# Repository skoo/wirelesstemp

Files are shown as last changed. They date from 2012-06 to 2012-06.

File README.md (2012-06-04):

wirelesstemp
============

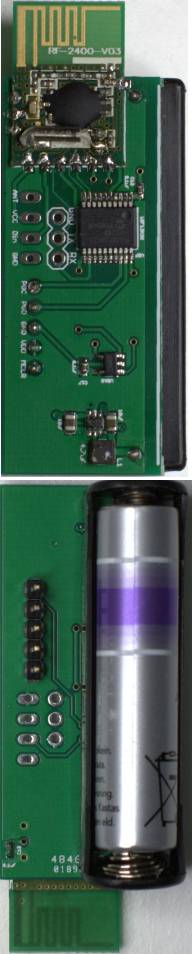
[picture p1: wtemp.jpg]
Wirelesstemp board


wirelesstemp is a wireless temperature sensor with following components:

- Microchip 18f13k22 microcontroller
- Microchip TC77 Thermal sensor with SPI interface
- RF-2400-V03 RF transmitter
- TPS61221 low input voltage boost converter
- 1.5 AAA battery

This 1.5V AAA battery operated temperature sensor sends measurement once each 65.5 seconds.
Sensor should operate for more than one year based on following measurements/assumptions:

- AAA battery holds 1000mAh.
- Sleep state consumes 90uA/65.5s
- Active state 40mA/15ms.

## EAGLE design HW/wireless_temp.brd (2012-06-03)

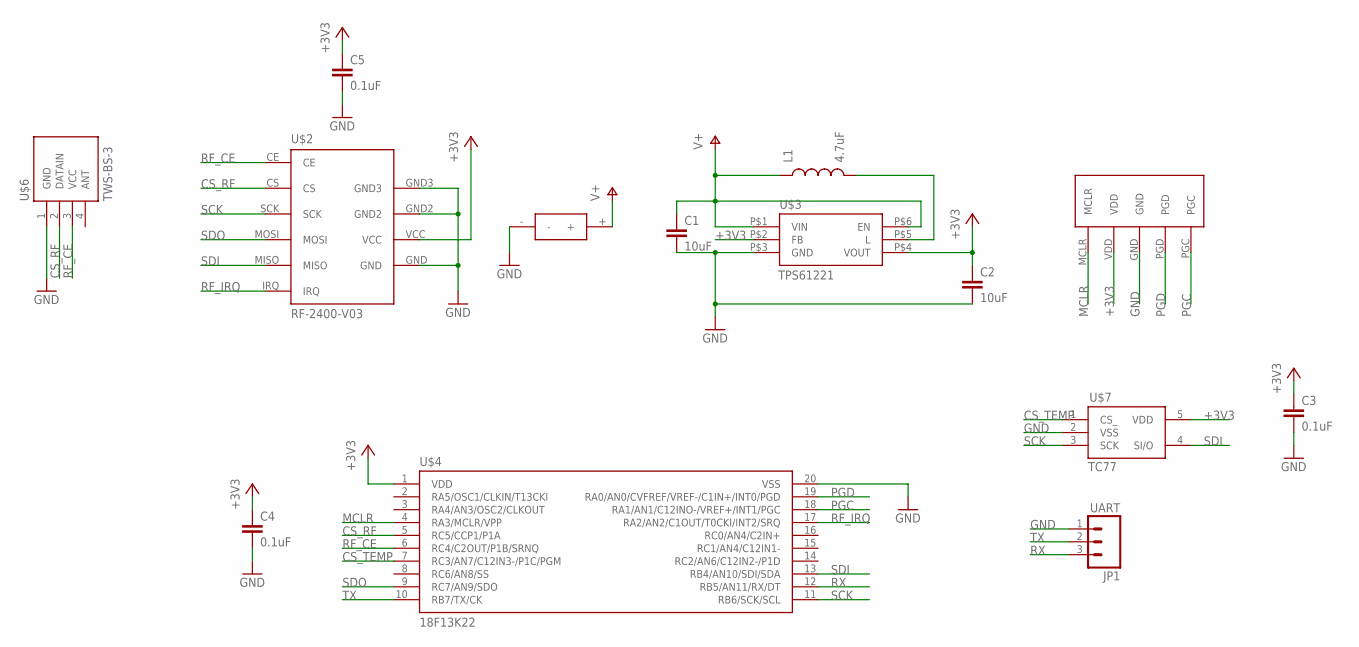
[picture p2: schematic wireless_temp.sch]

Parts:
C1, C2: 10uF; 0805
C3, C4, C5: 0.1uF; 0402-CAP
JP1: UART; 1X03
L1: 4.7uF; NR3015T
U$1: BAT_HOLDER; AAA
U$2: RF-2400-V03
U$3: TPS61221; SO6
U$4: 18F13K22; SSOP20
U$5: PIC-ICSP; ICSP
U$6: TWS-BS-3
U$7: TC77; SOT23-5

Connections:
+3V3: C2.1, C3.1, C4.1, C5.1, U$2.VCC, U$3.P$2 (FB), U$3.P$4 (VOUT), U$4.1 (VDD), U$5.VDD, U$7.5 (VDD)
CS_RF: U$2.CS, U$4.5 (RC5/CCP1/P1A), U$6.2 (DATAIN)
CS_TEMP: U$4.7 (RC3/AN7/C12IN3-/P1C/PGM), U$7.1 (CS_)
GND: C1.2, C2.2, C3.2, C4.2, C5.2, JP1.1, U$1.-, U$2.GND, U$2.GND2, U$2.GND3, U$3.P$3 (GND), U$4.20 (VSS), U$5.GND, U$6.1 (GND), U$7.2 (VSS)
MCLR: U$4.4 (RA3/MCLR/VPP), U$5.MCLR
unnamed: L1.P$2 (2), U$3.P$5 (L)
PGC: U$4.18 (RA1/AN1/C12INO-/VREF+/INT1/PGC), U$5.PGC
PGD: U$4.19 (RA0/AN0/CVFREF/VREF-/C1IN+/INT0/PGD), U$5.PGD
RF_CE: U$2.CE, U$4.6 (RC4/C2OUT/P1B/SRNQ), U$6.3 (VCC)
RF_IRQ: U$2.IRQ, U$4.17 (RA2/AN2/C1OUT/T0CKI/INT2/SRQ)
RX: JP1.3, U$4.12 (RB5/AN11/RX/DT)
SCK: U$2.SCK, U$4.11 (RB6/SCK/SCL), U$7.3 (SCK)
SDI: U$2.MISO, U$4.13 (RB4/AN10/SDI/SDA), U$7.4 (SI/O)
SDO: U$2.MOSI, U$4.9 (RC7/AN9/SDO)
TX: JP1.2, U$4.10 (RB7/TX/CK)
V+: C1.1, L1.P$1 (1), U$1.+, U$3.P$1 (VIN), U$3.P$6 (EN)

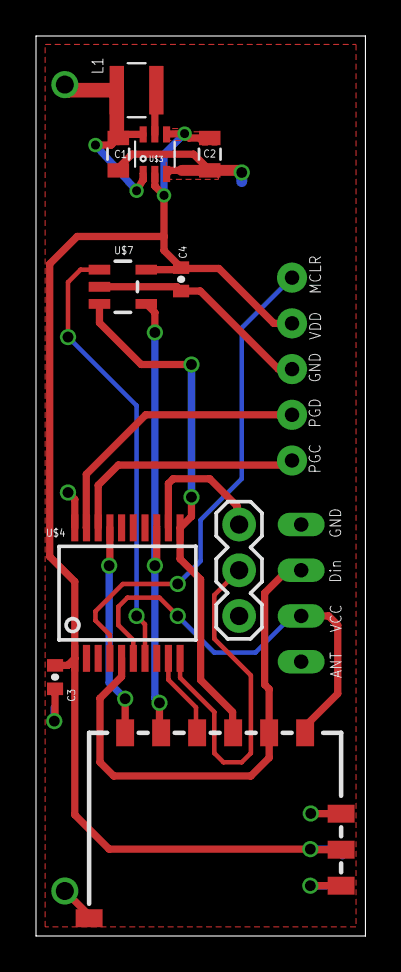
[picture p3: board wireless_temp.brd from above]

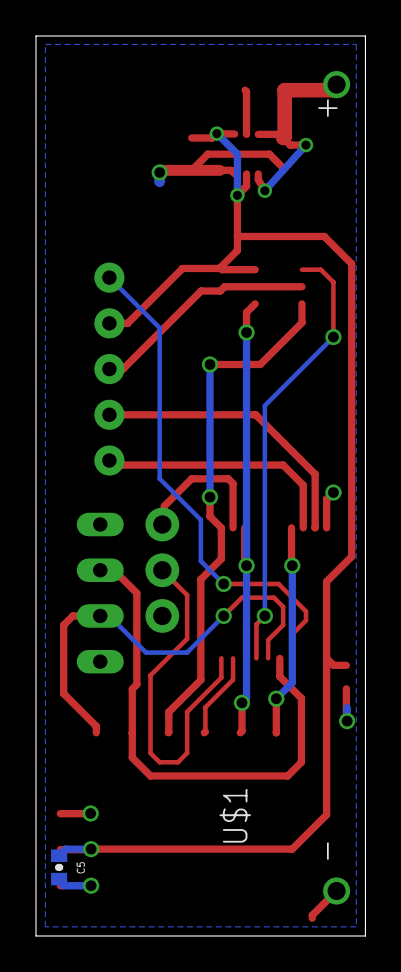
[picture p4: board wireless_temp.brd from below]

Board: 2 copper layers, 18.3 x 50.0 mm, 14 parts (2 on the bottom side), 16 nets.

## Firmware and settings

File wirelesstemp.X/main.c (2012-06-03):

#include "hw.h"
#include <bk2421.h>
#include "tc77.h"

#define _id 0xc3

//#define PULSE_COUNTER

static volatile unsigned short _pulse_count = 0;
static volatile unsigned char _timer_int;

static const unsigned char _tx_addr[5] = {'s', 'k', '-', 'w', 0x00};
static const unsigned char _rx_addr[5] = {'s', 'k', '-', 'w', _id};

/* 18f+tc77+step-up pull 89uA @ 1.5V when in sleep mode
 * 
 */

static void main_delay(void);
static void timer_delay(void);
static void rf_send_temp(int t);

void high_isr(void);

#pragma code high_vector=0x08
void interrupt_at_high_vector(void)
{
  _asm GOTO high_isr _endasm
}

#pragma code

void main(void)
{
    int t;

    ANSEL = 0;  /* all ports digital */
    ANSELH = 0;

    /* set unused pins as outputs */
    TRISA = 0b00000100; // RA2: RF2400 IRQ
    TRISB = 0b00010000; // R45: SDI
    TRISC = 0b00000000;

#ifdef PULSE_COUNTER
    TRISBbits.TRISB5 = 1;
    IOCBbits.IOCB5 = 1;
    INTCONbits.RABIE = 1;
#endif

    TC77_CS = 1;
    BK2421_CS = 1;

    SSPSTATbits.SMP = 1;
    SSPSTATbits.CKE = 1;
    SSPCON1bits.CKP = 0;
    /* TC77 has max SPI clock of 7MHz, RF has max 8MHz clock. */
    /* Using FOSC / 4 = 16/4 = 4MHz */
    SSPCON1bits.SSPM1 = 0;
    SSPCON1bits.WCOL = 0;
    SSPCON1bits.SSPEN = 1;

    WDTCONbits.SWDTEN = 1; // watchdog is set to ~65.5s with post scaler

    T1CON = 0b10110000; // 1:8 prescaler

    PIE1bits.TMR1IE = 1;
    INTCONbits.PEIE = 1;
    INTCONbits.GIE = 1;

    bk2421_init(_rx_addr, _tx_addr);

    tc77_mode(TC77_CONTCONV);
    Delay1KTCYx(250);
    Delay1KTCYx(150);

    while (1) {
        int timeout = 100;
        do {
             Delay1KTCYx(1);
            t = tc77_read_temp();
        } while (t == TC77_NOT_READY && timeout-- > 0);

        bk2421_rf_power_mode(1);
        rf_send_temp(t);
        bk2421_rf_power_mode(0);

        tc77_mode(TC77_SHUTDOWN); /* 0.1uA when in shutdown mode */

        main_delay();

        /* Enable tc77 temperature conversion,
         * It takes 300.400ms for first conversion.
         * tc77 consumes 250uA in continuous conversion mode */
        tc77_mode(TC77_CONTCONV); 

        /* Set timer for ~524ms (1:8 tmr1 prescaler) */
        TMR1H = 0xc0;
        TMR1L = 0x00;
        T1CONbits.TMR1ON = 1;
        
        timer_delay();

        T1CONbits.TMR1ON = 0;
        PIR1bits.TMR1IF = 0;
    }
}

#ifdef PULSE_COUNTER

/*
 * System does not sleep when pulse counter is enabled as it must
 * keep counting pulses from RB5.
 */

void main_delay(void)
{
    unsigned char i;

    ClrWdt();

    /* set timer to 2048ms (1:8 tmr1 prescaler) */
    TMR1H = 0x00;
    TMR1L = 0x00;

    /* sleep for 30 seconds */
    for (i = 0; i < 15; i++) {
        _timer_int = 0;
        T1CONbits.TMR1ON = 1;
        while (_timer_int == 0);
        T1CONbits.TMR1ON = 0;
    }
}

void timer_delay(void)
{
    _timer_int = 0;
    while (_timer_int == 0);
}

#else
void main_delay(void)
{
    OSCCONbits.IDLEN = 0;
    Sleep(); /* WDT wakeup after ~65s */
}

void timer_delay(void)
{
    OSCCONbits.IDLEN = 1;
    Sleep(); /* Timer1 wakeup */
}
#endif

void rf_send_temp(int t)
{
    static unsigned char buf[5];

    buf[0] = t >> 8;
    buf[1] = t & 0xff;
    buf[2] = _id;

#ifdef PULSE_COUNTER
    INTCONbits.RABIE = 0;
    buf[3] = _pulse_count >> 8;
    buf[4] = _pulse_count & 0xff;
    INTCONbits.RABIE = 1;
    bk2421_send_packet(buf, 5);
#else
    bk2421_send_packet(buf, 3);
#endif
}

#pragma code
/*****************High priority ISR **************************/

#pragma interrupt high_isr
void high_isr (void)
{
    if (PIR1bits.TMR1IF) {
        _timer_int++;
        PIR1bits.TMR1IF = 0;
    }

    if (INTCONbits.RABIF) {
        if (PORTBbits.RB5 == 0) {
            _pulse_count++;
        }
        INTCONbits.RABIF = 0;
    }
}

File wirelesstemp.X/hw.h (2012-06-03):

#ifndef _HW_H_
#define _HW_H_

#include <p18f13k22.h>
#include <delays.h>

/* TC77 HW config ----------------------------------------------------------- */

#define TC77_CS     PORTCbits.RC3

#define tc77_spi_write(x) \
    SSPBUF = x; \
    while (!SSPSTATbits.BF);

#define tc77_spi_buf    SSPBUF
#define TC77_SDI_TRIS   TRISBbits.TRISB4
#define TC77_SDI_PORT   PORTBbits.RB4

/* BK2421 HW config ----------------------------------------------------------*/

#define BK2421_CS   PORTCbits.RC5
#define BK2421_CE   PORTCbits.RC4
#define BK2421_IRQ  PORTAbits.RA2

#define bk2421_spi_write(x) \
    SSPBUF = x; \
    while (!SSPSTATbits.BF);

#define bk2421_spi_buf    SSPBUF

/* for delays used in bk2421 init */
#define bk2421_delay_ms(x) Delay1KTCYx(x); /* @ 1MHz */
#define bk2421_delay_us(x) Delay10TCYx((x+9)/10); /* @ 1MHz */

#endif /* _HW_H_ */

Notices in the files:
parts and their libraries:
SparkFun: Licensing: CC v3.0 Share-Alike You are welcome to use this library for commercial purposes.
